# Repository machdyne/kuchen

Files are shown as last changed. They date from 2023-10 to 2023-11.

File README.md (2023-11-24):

# Kuchen Computer

Kuchen is an FPGA computer designed by Lone Dynamics Corporation.

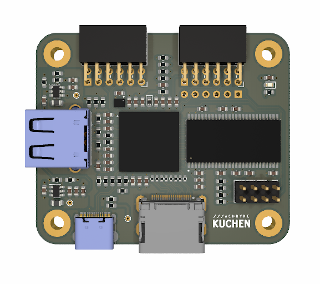
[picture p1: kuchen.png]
Kuchen FPGA Computer


This repo contains PCB layouts, schematics, pinouts, example gateware and documentation.

Find more information on the [Kuchen product page](https://machdyne.com/product/kuchen-computer/).

## Blinky 

Building the blinky example requires [Yosys](https://github.com/YosysHQ/yosys), [nextpnr-ice40](https://github.com/YosysHQ/nextpnr) and [IceStorm](https://github.com/YosysHQ/icestorm).

Assuming they are installed, you can simply type `make` to build the gateware, which will be written to output/blinky.bin. You can then use [ldprog](https://github.com/machdyne/ldprog) to write the gateware to the device over the ISP header, or use the USB DFU bootloader:

```
$ dfu-util -a 0 -D output/blinky.bin
```

Exit the bootloader and continue booting:

```
sudo dfu-util -e -a 0
```

## Zucker

[Zucker](https://github.com/machdyne/zucker) is a RISC-V SOC that supports Kuchen.

## USB Bootloader

Kuchen supports updating the flash MMOD over its USB-C port with the USB DFU (Device Firmware Upgrade) protocol. When Kuchen powers on (or restarts) the USB bootloader waits 5 seconds for a USB command and then continues the boot process, if it receives a command it will wait until the device is detached (with `dfu-util -e`) or rebooted (with `ldprog -r`).

Kuchen ships with the DFU bootloader on the MMOD. In order to re-install the USB bootloader you will need to use the ISP header and [ldprog](https://github.com/machdyne/ldprog). Make sure you have first installed the software required to build the Blinky example above.

```
git clone https://github.com/machdyne/tinydfu-bootloader
cd tinydfu-bootloader/boards/kuchen
make
make prog
```

Now you can program the flash MMOD over USB:

```
ldprog -r
sudo dfu-util -a 0 -D zucker/output/kuchen/soc.bin
sudo dfu-util -a 1 -D zucker/apps/lix/lix.bin
```

Exit the bootloader and continue booting:

```
sudo dfu-util -e -a 0
```

## ISP Header

The ISP header can be used to program the FPGA SRAM as well as the MMOD flash memory. 

```
7 5 3 1
8 6 4 2
```

| Pin | Signal |
| --- | --- |
| 1 | CSPI\_SS |
| 2 | CSPI\_SCK |
| 3 | CSPI\_SI |
| 4 | CSPI\_SO |
| 5 | CRESET |
| 6 | CDONE |
| 7 | GND |
| 8 | PWR5V0 |

## Board Revisions

| Revision | Notes |
| --- | ----- |
| V0 | Initial production boards |
| V1 | Move DQ7 from K14 to J14 |

## License

The contents of this repo are released under the [Lone Dynamics Open License](LICENSE.md).

Note: You can use these designs for commercial purposes but we ask that instead of producing exact clones, that you either replace our trademarks and logos with your own or add your own next to ours.

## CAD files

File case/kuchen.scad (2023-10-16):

/*
 * Kuchen Case
 * Copyright (c) 2023 Lone Dynamics Corporation. All rights reserved.
 *
 * required hardware:
 *  - 4 x M3 x 20mm countersunk bolts
 *  - 4 x M3 nuts
 *
 */

$fn = 100;

board_width = 50;
board_thickness = 1.5;
board_length = 60;
board_height = 1.6;
board_spacing = 2;

wall = 1.5;

top_height = 10;
bottom_height = 10;

//mdk_board();

//translate([0,0,15])
//	mdk_case_top();

translate([0,0,-15])
	mdk_case_bottom();

module mdk_board() {
	
	difference() {
		color([0,0.5,0])
			roundedcube(board_width,board_length,board_thickness,3);
		translate([5, 5, -1]) cylinder(d=3.2, h=10);
		translate([5, 55, -1]) cylinder(d=3.2, h=10);
		translate([45, 5, -1]) cylinder(d=3.2, h=10);
		translate([45, 55, -1]) cylinder(d=3.2, h=10);
	}	
	
}

module mdk_case_top() {
	
	difference() {
				
		color([0.5,0.5,0.5])
			roundedcube(board_width+(wall*2),board_length+(wall*2),top_height,2.5);

		// cutouts
			
		translate([2,9.5,-2])
			roundedcube(board_width-1.25,board_length-16,10.25,2.5);

		translate([9.5,3,-2])
			roundedcube(board_width-16,board_length-3,10.25,2.5);			
	
		translate([wall, wall, 0]) {

			// vents
			translate([50/2-(25/2),50,0]) cube([25,1,20]);
			translate([50/2-(25/2),45,0]) cube([25,1,20]);
			translate([50/2-(25/2),40,0]) cube([25,1,20]);			
	
			// USBC
			translate([30,14-(9.5/2),-1]) cube([30,9.5,3.5+1]);

			// HDMI
			translate([30,32-(15.5/2),-1]) cube([30,15.5,6.2+1]);
	
			// USBA
			translate([25-(15/2),-5,0]) cube([15,10,7.2+1]);
	

			// PMODA
			translate([-10,18.595-(16/2),0]) cube([25,16,5.1]);

			// PMODB
			translate([-10,41.455-(16/2),0]) cube([25,16,5.1]);
			
			// bolt holes
			translate([5, 5, -21]) cylinder(d=3.5, h=40);
			translate([5, 55, -21]) cylinder(d=3.5, h=40);
			translate([45, 5, -20]) cylinder(d=3.5, h=40);
			translate([45, 55, -21]) cylinder(d=3.5, h=40);

			// flush mount bolt holes
			translate([5, 5, top_height-1.5]) cylinder(d=5.25, h=4);
			translate([5, 55, top_height-1.5]) cylinder(d=5.25, h=4);
			translate([45, 5, top_height-1.5]) cylinder(d=5.25, h=4);
			translate([45, 55, top_height-1.5]) cylinder(d=5.25, h=4);

			// kuchen text
			rotate(270)
				translate([-18.5,25-3,top_height-0.5])
					linear_extrude(1)
						text("K U C H E N", size=4, halign="center",
							font="Ubuntu:style=Bold");

		}
		
	}	
}

module mdk_case_bottom() {
	
	difference() {
		color([0.5,0.5,0.5])
			roundedcube(board_width+(wall*2),board_length+(wall*2),bottom_height,2.5);
		
		// cutouts
		translate([3,10,1.5])
			roundedcube(board_width-3,board_length-17,10,2.5);
				
		translate([10.5,2.5,1.5])
			roundedcube(board_width-17.5,board_length-2,10,2.5);

		translate([wall, wall, 0]) {
			
		// board cutout
		translate([0,0,bottom_height-board_height])
			roundedcube(board_width+0.2,board_length+0.2,board_height+1,2.5);

		translate([wall, wall, 0]) {

			// USBC
			translate([38.5,14-(9.5/2),5]) cube([10.20,9.5,10.5+1]);

		}

		// bolt holes
		translate([5, 5, -11]) cylinder(d=3.2, h=25);
		translate([5, 55, -11]) cylinder(d=3.2, h=25);
		translate([45, 5, -11]) cylinder(d=3.2, h=25);
		translate([45, 55, -11]) cylinder(d=3.2, h=25);

		// nut holes
		translate([5, 5, -1]) cylinder(d=7, h=4, $fn=6);
		translate([5, 55, -1]) cylinder(d=7, h=4, $fn=6);
		translate([45, 5, -1]) cylinder(d=7, h=4, $fn=6);
		translate([45, 55, -1]) cylinder(d=7, h=4, $fn=6);

		}
		
	}	
}

// https://gist.github.com/tinkerology/ae257c5340a33ee2f149ff3ae97d9826
module roundedcube(xx, yy, height, radius)
{
    translate([0,0,height/2])
    hull()
    {
        translate([radius,radius,0])
        cylinder(height,radius,radius,true);

        translate([xx-radius,radius,0])
        cylinder(height,radius,radius,true);

        translate([xx-radius,yy-radius,0])
        cylinder(height,radius,radius,true);

        translate([radius,yy-radius,0])
        cylinder(height,radius,radius,true);
    }
}

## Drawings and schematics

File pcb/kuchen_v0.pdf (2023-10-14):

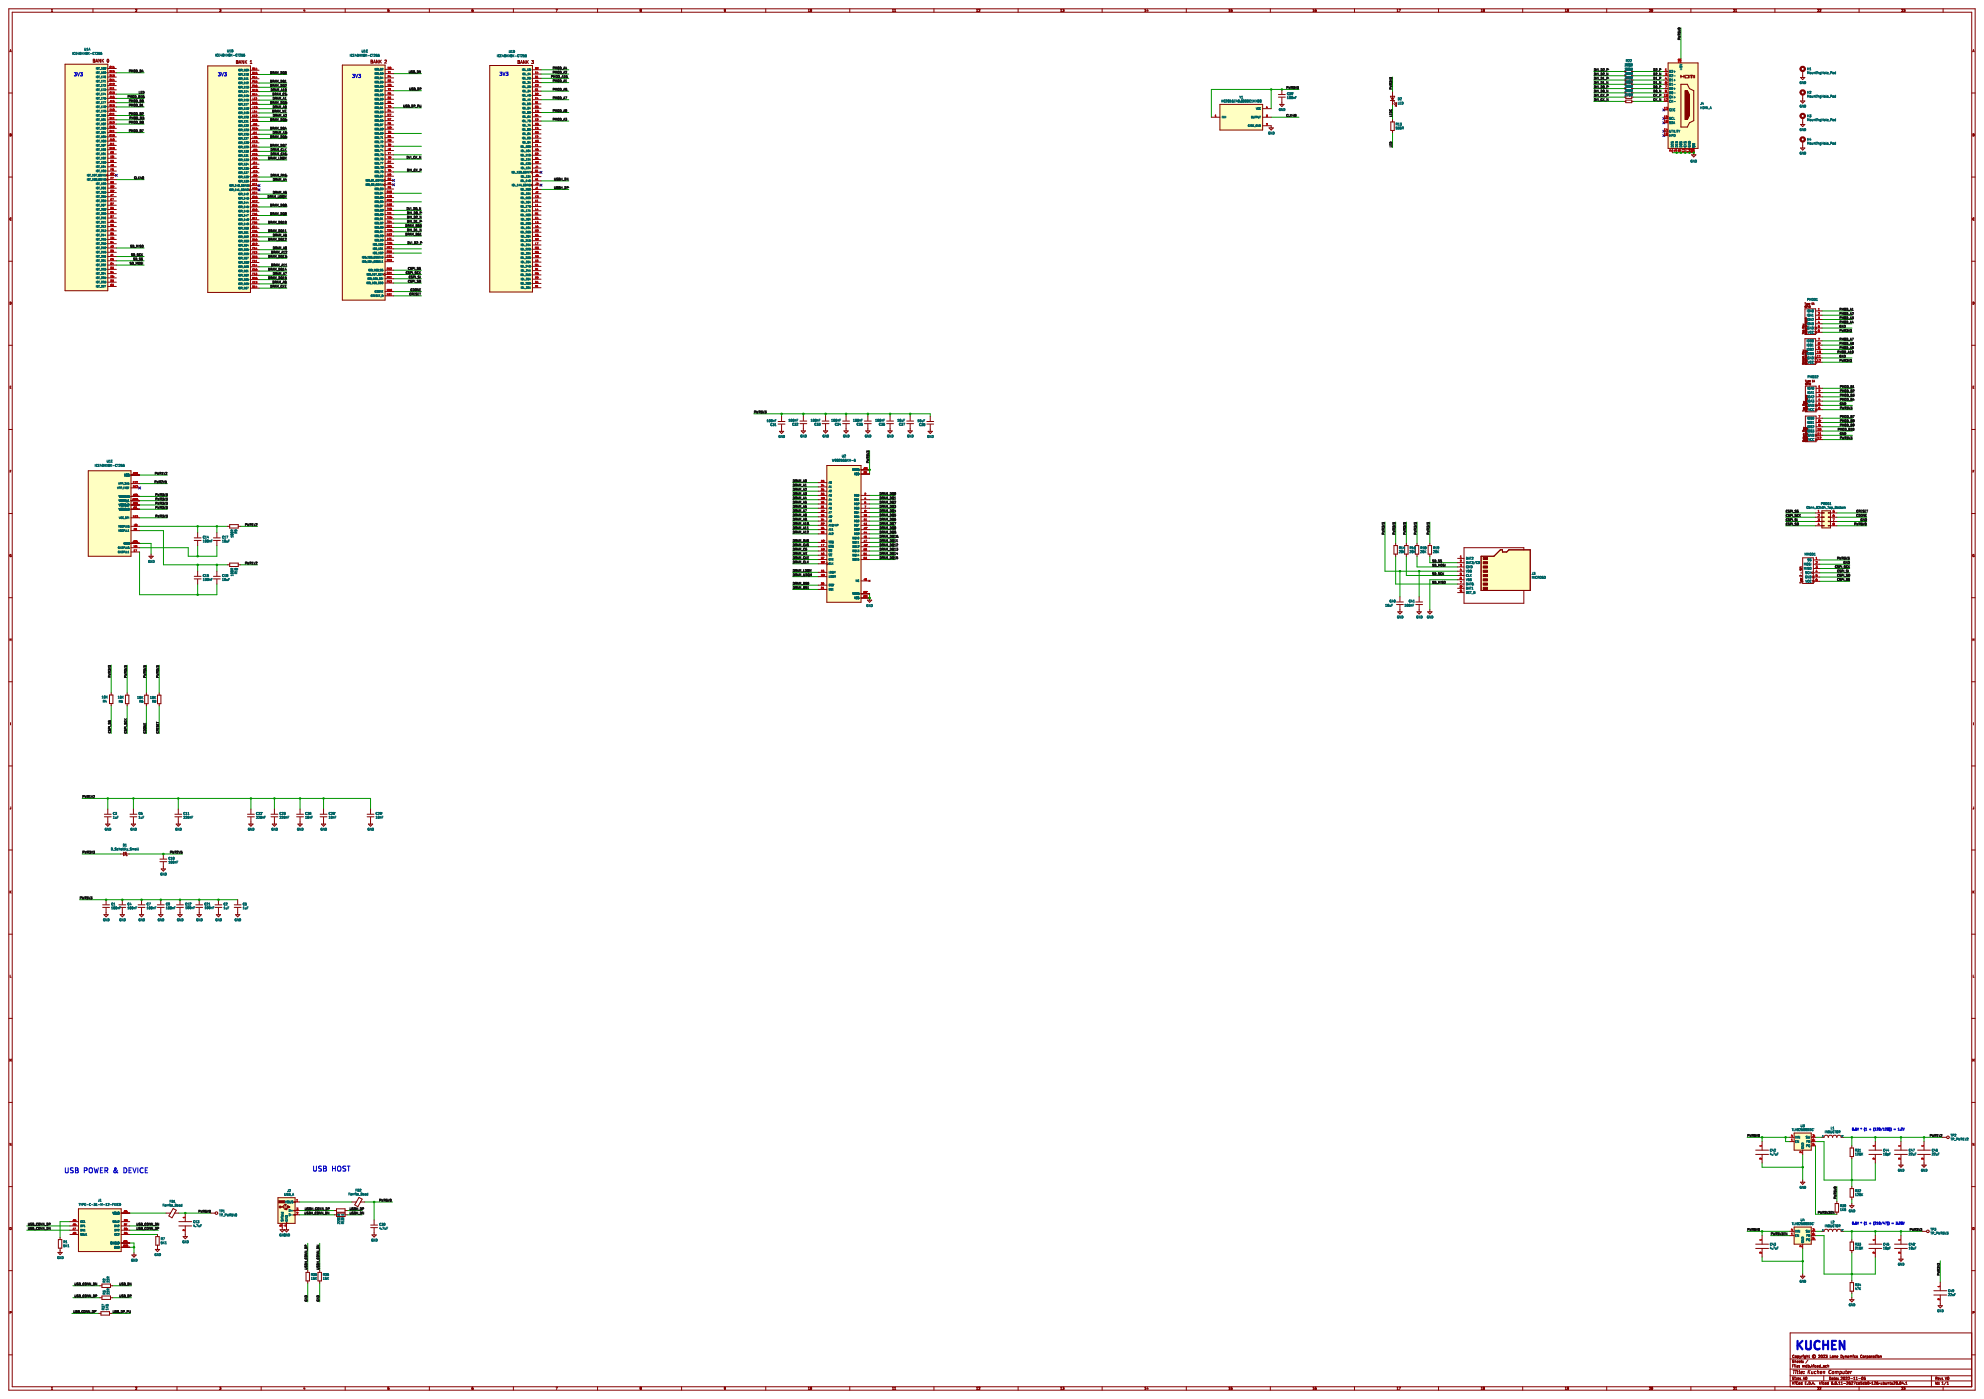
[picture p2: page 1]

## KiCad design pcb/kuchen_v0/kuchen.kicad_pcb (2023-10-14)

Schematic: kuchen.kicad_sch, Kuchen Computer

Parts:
C1, C4, C7, C9, C10, C12, C14, C15, C21, C31, C32, C33, C34, C35, C36, C39: 100nF; C_0603_1608Metric
C2, C3, C5, C6: 1uF; C_0603_1608Metric
C11, C22, C23: 220nF; C_0603_1608Metric
C13, C30: 4.7uF; R_0603_1608Metric
C17, C18, C37, C38, C48: 10uF; C_0603_1608Metric
C26, C28, C29: 10nF; C_0603_1608Metric
C40: 10uF; R_0603_1608Metric
C41: 100nF; R_0603_1608Metric
C42, C43: 4.7uF; C_0603_1608Metric
C44, C45: 10pF; C_0603_1608Metric
C46, C47, C49: 22uF; C_0603_1608Metric
D1: D_Schottky_Small; D_0603_1608Metric
D2: LED; LED_0603_1608Metric
FB1, FB2: Ferrite_Bead; R_0603_1608Metric
H1, H2, H3, H4: MountingHole_Pad; MountingHole_3.2mm_M3_Pad
J1: TYPE-C-31-M-12-FIXED; USB_C_Receptacle_HRO_TYPE-C-31-M-12-BIG-PADS; PARTREV A
J2: USB_A; USB_A_Stewart_SS-52100-001_Horizontal
J3: MICROSD; TF-018B-H15
J4: HDMI_A; HDMI_TE_1827059-3-FIXED
L1, L2: INDUCTOR; L_0805_2012Metric
MMOD1: PMOD-Device-x1-Type-2-SPI; PinSocket_1x06_P2.54mm_Horizontal
PMOD1, PMOD2: PMOD-Device-x2-Type-1A-GPIO; PMOD_2x06_HOST
PROG1: Conn_02x04_Top_Bottom; PinHeader_2x04_P2.54mm_Vertical
R1, R7: 5K1; R_0603_1608Metric
R2, R3, R11, R12: 22R; R_0603_1608Metric
R4, R5, R6, R8: 10K; R_0603_1608Metric
R9, R10: 100R; R_0603_1608Metric
R13: 536R; R_0603_1608Metric
R14, R16, R18, R19: 20K; R_0603_1608Metric
R22, R23, R24, R25, R26, R27, R28, R29: 270R; R_0402_1005Metric
R30, R37: 1K5; R_0603_1608Metric
R31, R32: 120K; R_0603_1608Metric
R33: 210K; R_0603_1608Metric
R34: 47K; R_0603_1608Metric
R35, R36: 15K; R_0603_1608Metric
TP1: TP_PWR5V0; TestPoint_THTPad_D1.0mm_Drill0.5mm
TP2: TP_PWR1V2; TestPoint_THTPad_D1.0mm_Drill0.5mm
TP3: TP_PWR3V3; TestPoint_THTPad_D1.0mm_Drill0.5mm
U1: ICE40HX8K-CT256; BGA256C80P16X16_1400X1400X170; PART_REV 3.4
U2: W9825G6KH-6; SOP80P1176X120-54N; PARTREV A05
U3, U4: TLV62568DDC; SOT-23-6
Y1: KC2016Z48.0000C1KX00; OSC_KC2016Z13.5600C1KX00; PARTREV November 2020

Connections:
/CDONE: PROG1.6, R6.1, U1.M10 (CDONE)
/CK_N: J4.12 (CK-), R29.2
/CK_P: J4.10 (CK+), R28.2
/CLK48: U1.F7 (IOT_198_GBIN0), Y1.3 (OUTPUT)
/CRESET: PROG1.5, R8.1, U1.N11 (CRESET_B)
/CSPI_SCK: MMOD1.3 (MISO), PROG1.2, R5.1, U1.R11 (IOB_107_SCK)
/CSPI_SI: MMOD1.4 (SCK), PROG1.3, U1.P11 (IOB_106_SDI)
/CSPI_SO: MMOD1.5 (GND), PROG1.4, U1.P12 (IOB_105_SDO)
/CSPI_SS: MMOD1.6 (VCC), PROG1.1, R4.1, U1.R12 (IOB_108_SS)
/D0_N: J4.9 (D0-), R27.2
/D0_P: J4.7 (D0+), R26.2
/D1_N: J4.6 (D1-), R25.2
/D1_P: J4.4 (D1+), R24.2
/D2_N: J4.3 (D2-), R23.2
/D2_P: J4.1 (D2+), R22.2
/DRAM_A0: U1.L13 (IOR_118), U2.23 (A0)
/DRAM_A1: U1.L12 (IOR_116), U2.24 (A1)
/DRAM_A2: U1.K12 (IOR_120), U2.25 (A2)
/DRAM_A3: U1.J11 (IOR_126), U2.26 (A3)
/DRAM_A4: U1.H13 (IOR_139), U2.29 (A4)
/DRAM_A5: U1.H14 (IOR_142), U2.30 (A5)
/DRAM_A6: U1.G13 (IOR_152), U2.31 (A6)
/DRAM_A7: U1.F13 (IOR_162), U2.32 (A7)
/DRAM_A8: U1.F14 (IOR_155), U2.33 (A8)
/DRAM_A9: U1.E13 (IOR_166), U2.34 (A9)
/DRAM_A10: U1.M13 (IOR_114), U2.22 (A10/AP)
/DRAM_A11: U1.E14 (IOR_160), U2.35 (A11)
/DRAM_A12: U1.F12 (IOR_156), U2.36 (A12)
/DRAM_BS0: U1.M11 (IOB_93), U2.20 (BS0)
/DRAM_BS1: U1.N12 (IOB_98), U2.21 (BS1)
/DRAM_CAS: U1.K15 (IOR_131), U2.17 (~CAS)
/DRAM_CKE: U1.D14 (IOR_167), U2.37 (CKE)
/DRAM_CLK: U1.J15 (IOR_130), U2.38 (CLK)
/DRAM_CS: U1.M14 (IOR_115), U2.19 (~CS)
/DRAM_DQ0: U1.R15 (IOR_110), U2.2 (DQ0)
/DRAM_DQ1: U1.P15 (IOR_112), U2.4 (DQ1)
/DRAM_DQ2: U1.P16 (IOR_113), U2.5 (DQ2)
/DRAM_DQ3: U1.N16 (IOR_117), U2.7 (DQ3)
/DRAM_DQ4: U1.M15 (IOR_123), U2.8 (DQ4)
/DRAM_DQ5: U1.M16 (IOR_121), U2.10 (DQ5)
/DRAM_DQ6: U1.L16 (IOR_127), U2.11 (DQ6)
/DRAM_DQ7: U1.K14 (IOR_129), U2.13 (DQ7)
/DRAM_DQ8: U1.G15 (IOR_145), U2.42 (DQ8)
/DRAM_DQ9: U1.F16 (IOR_147), U2.44 (DQ9)
/DRAM_DQ10: U1.F15 (IOR_149), U2.45 (DQ10)
/DRAM_DQ11: U1.E16 (IOR_151), U2.47 (DQ11)
/DRAM_DQ12: U1.D16 (IOR_153), U2.48 (DQ12)
/DRAM_DQ13: U1.D15 (IOR_157), U2.50 (DQ13)
/DRAM_DQ14: U1.C16 (IOR_161), U2.51 (DQ14)
/DRAM_DQ15: U1.B16 (IOR_165), U2.53 (DQ15)
/DRAM_LDQM: U1.K16 (IOR_133), U2.15 (LDQM)
/DRAM_RAS: U1.J16 (IOR_138), U2.18 (~RAS)
/DRAM_UDQM: U1.G16 (IOR_143), U2.39 (UDQM)
/DRAM_WE: U1.L14 (IOR_119), U2.16 (~WE)
/DVI_CK_N: R29.1, U1.T8 (IOB_76)
/DVI_CK_P: R28.1, U1.T9 (IOB_79)
/DVI_D0_N: R27.1, U1.T10 (IOB_88)
/DVI_D0_P: R26.1, U1.T11 (IOB_89)
/DVI_D1_N: R25.1, U1.T13 (IOB_94)
/DVI_D1_P: R24.1, U1.T14 (IOB_92)
/DVI_D2_N: R23.1, U1.T15 (IOB_91)
/DVI_D2_P: R22.1, U1.T16 (IOB_100)
/LED: R13.2, U1.C13 (IOT_174)
/LEDC: D2.1 (K), R13.1
/PMOD_A1: PMOD1.1 (IOA0), U1.F5 (IOL_2A)
/PMOD_A2: PMOD1.2 (IOA1), U1.E4 (IOL_1A)
/PMOD_A3: PMOD1.3 (IOA2), U1.E2 (IOL_7B)
/PMOD_A4: PMOD1.4 (IOA3), U1.B2 (IOL_1B)
/PMOD_A7: PMOD1.7 (IOB0), U1.F4 (IOL_4A)
/PMOD_A8: PMOD1.8 (IOB1), U1.E3 (IOL_6B)
/PMOD_A9: PMOD1.9 (IOB2), U1.C1 (IOL_3A)
/PMOD_A10: PMOD1.10 (IOB3), U1.B1 (IOL_2B)
/PMOD_B1: PMOD2.1 (IOA0), U1.B13 (IOT_178)
/PMOD_B2: PMOD2.2 (IOA1), U1.C11 (IOT_180)
/PMOD_B3: PMOD2.3 (IOA2), U1.D11 (IOT_181)
/PMOD_B4: PMOD2.4 (IOA3), U1.B15 (IOT_169)
/PMOD_B7: PMOD2.7 (IOB0), U1.B11 (IOT_184)
/PMOD_B8: PMOD2.8 (IOB1), U1.B12 (IOT_182)
/PMOD_B9: PMOD2.9 (IOB2), U1.A15 (IOT_177)
/PMOD_B10: PMOD2.10 (IOB3), U1.A16 (IOT_176)
/PWR1V2: C3.1, C6.1, C11.1, C22.1, C23.1, C26.1, C28.1, C29.1, C44.1, C46.1, C47.1, L1.2, R9.1, R10.1, R31.1, TP2.1, U1.A14 (VCC), U1.F6 (VCC), U1.F10 (VCC), U1.K6 (VCC), U1.K10 (VCC), U1.L2 (VCC)
/PWR2V5: C10.1, D1.1 (K), U1.E12 (VPP_2V5)
/PWR3V3: C1.1, C2.1, C4.1, C5.1, C7.1, C9.1, C12.1, C21.1, C31.2, C32.2, C33.2, C34.2, C35.2, C36.2, C37.2, C38.2, C39.1, C40.1, C41.1, C45.1, C48.1, C49.1, D1.2 (A), D2.2 (A), J3.4 (VDD), L2.2, MMOD1.1 (SS), PMOD1.6 (VCC), PMOD1.12 (VCC), PMOD2.6 (VCC), PMOD2.12 (VCC), R4.2, R5.2, R6.2, R8.2, R14.1, R16.1, R18.1, R19.1, R33.1, TP3.1, U1.A3 (VCCIO_0), U1.A8 (VCCIO_0), U1.A13 (VCCIO_0), U1.C15 (VCCIO_1), U1.E1 (VCCIO_3), U1.F8 (VCCIO_0), U1.G6 (VCCIO_3), U1.H10 (VCCIO_1), U1.H15 (VCCIO_1), U1.J6 (VCCIO_3), U1.K8 (VCCIO_2), U1.N1 (VCCIO_3), U1.N13 (VCC_SPI), U1.N15 (VCCIO_1), U1.P3 (VCCIO_2), U1.R8 (VCCIO_2), U1.R13 (VCCIO_2), U2.1 (VDD), U2.3 (VDDQ), U2.9 (VDDQ), U2.14 (VDD), U2.27 (VDD), U2.43 (VDDQ), U2.49 (VDDQ), Y1.1 (INH), Y1.4 (VCC)
/PWR3V3EN: R30.2, U3.5 (PG), U4.1 (EN)
/PWR5V0: C13.1, C30.1, C42.1, C43.1, FB1.1, FB2.1, J4.18 (+5V), PROG1.8, R30.1, TP1.1, U3.1 (EN), U3.4 (VIN), U4.4 (VIN)
/SD_MISO: J3.7 (DAT0), R14.2, U1.A2 (IOT_218)
/SD_MOSI: J3.3 (CMD), R18.2, U1.C4 (IOT_222)
/SD_SCK: J3.5 (CLK), R16.2, U1.A1 (IOT_220)
/SD_SS: J3.2 (DAT3/CD), R19.2, U1.C5 (IOT_221)
/USBH_CONN_DN: J2.2 (D-), R12.2, R36.1
/USBH_CONN_DP: J2.3 (D+), R11.2, R35.1
/USBH_DN: R12.1, U1.H1 (IOL_14B)
/USBH_DP: R11.1, U1.J1 (IOL_15B)
/USB_CONN_DN: J1.A7 (DN1), J1.B7 (DN2), R2.1
/USB_CONN_DP: J1.A6 (DP1), J1.B6 (DP2), R3.1, R37.1
/USB_DN: R2.2, U1.T1 (IOB_53)
/USB_DP: R3.2, U1.T2 (IOB_57)
/USB_DP_PU: R37.2, U1.T3 (IOB_61)
GND: C1.2, C2.2, C3.2, C4.2, C5.2, C6.2, C7.2, C9.2, C10.2, C11.2, C12.2, C13.2, C21.2, C22.2, C23.2, C26.2, C28.2, C29.2, C30.2, C31.1, C32.1, C33.1, C34.1, C35.1, C36.1, C37.1, C38.1, C39.2, C40.2, C41.2, C42.2, C43.2, C46.2, C47.2, C48.2, C49.2, H1.1, H2.1, H3.1, H4.1, J1.A1 (GND), J1.A12 (GND), J1.B1 (GND), J1.B12 (GND), J1.S1 (SHIELD), J1.S2 (SHIELD), J1.S3 (SHIELD), J1.S4 (SHIELD), J2.4 (GND), J2.5 (Shield), J3.6 (VSS), J4.2 (D2S), J4.5 (D1S), J4.8 (D0S), J4.11 (CKS), J4.17 (GND), J4.S1 (SH), J4.S2 (SH), J4.S3 (SH), J4.S4 (SH), MMOD1.2 (MOSI), PMOD1.5 (GND), PMOD1.11 (GND), PMOD2.5 (GND), PMOD2.11 (GND), PROG1.7, R1.2, R7.2, R32.2, R34.2, R35.2, R36.2, U1.A4 (GND), U1.A12 (GND), U1.E15 (GND), U1.G7 (GND), U1.G8 (GND), U1.G9 (GND), U1.H7 (GND), U1.H8 (GND), U1.H9 (GND), U1.J7 (GND), U1.J8 (GND), U1.J9 (GND), U1.K2 (GND), U1.K7 (GND), U1.L15 (GND), U1.R7 (GND), U1.T4 (GND), U1.T12 (GND), U2.6 (VSSQ), U2.12 (VSSQ), U2.28 (VSS), U2.41 (VSS), U2.46 (VSSQ), U2.52 (VSSQ), U2.54 (VSS), U3.2 (GND), U4.2 (GND), Y1.2 (CASE_GND)
unnamed: C14.1, C17.1, R9.2, U1.L8 (VCCPLL0)
unnamed: C14.2, C17.2, U1.N8 (GNDPLL0)
unnamed: C15.1, C18.1, R10.2, U1.E8 (VCCPLL1)
unnamed: C15.2, C18.2, U1.E7 (GNDPLL1)
unnamed: C44.2, R31.2, R32.1, U3.6 (FB)
unnamed: C45.2, R33.2, R34.1, U4.6 (FB)
unnamed: FB1.2, J1.A4 (VBUS), J1.A9 (VBUS), J1.B4 (VBUS), J1.B9 (VBUS)
unnamed: FB2.2, J2.1 (VBUS)
unnamed: J1.A5 (CC1), R1.1
unnamed: J1.B5 (CC2), R7.1
unnamed: L1.1, U3.3 (SW)
unnamed: L2.1, U4.3 (SW)

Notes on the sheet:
0.6V * (1 + (120/120)) = 1.2V
3V3
KUCHEN
0.6V * (1 + (210/47)) = 3.28V
USB HOST
USB POWER & DEVICE

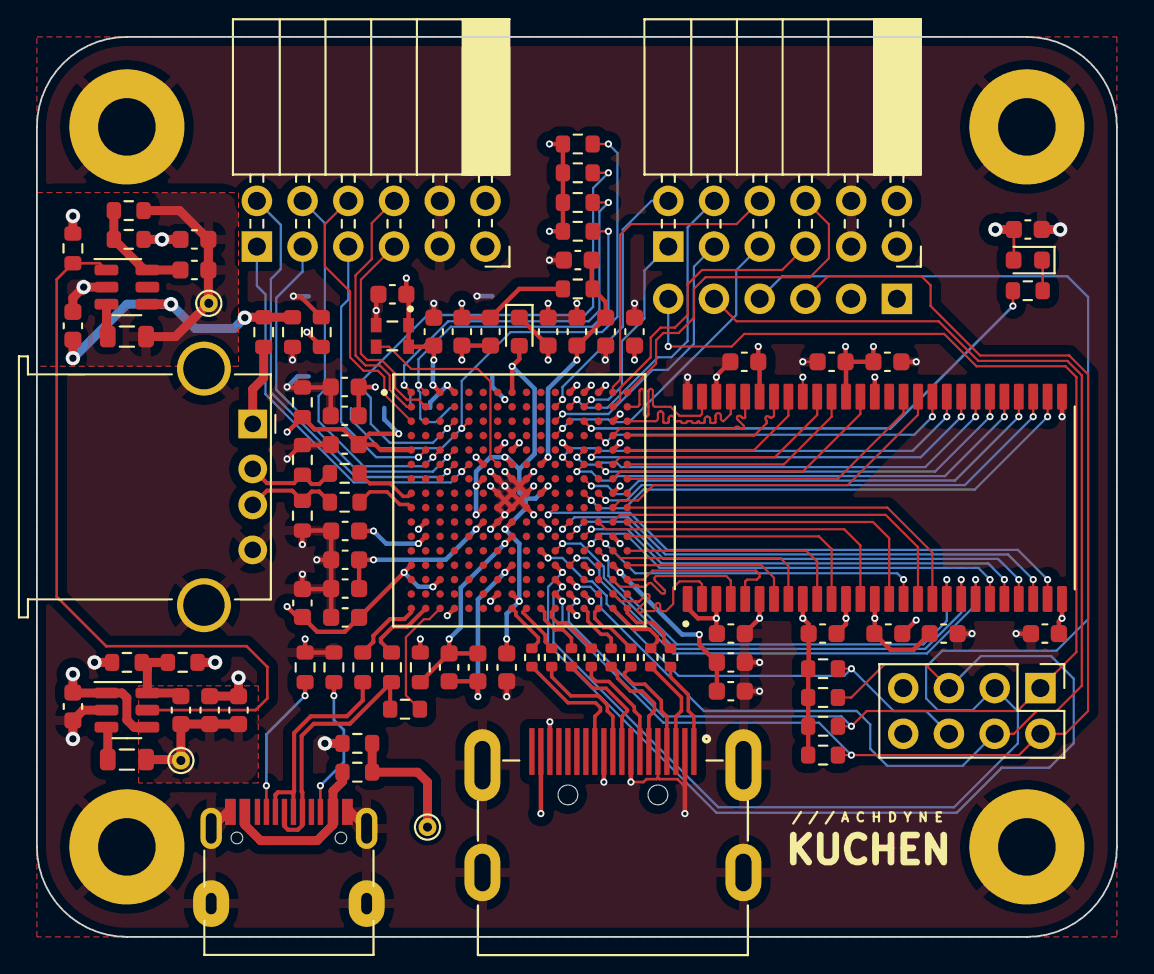
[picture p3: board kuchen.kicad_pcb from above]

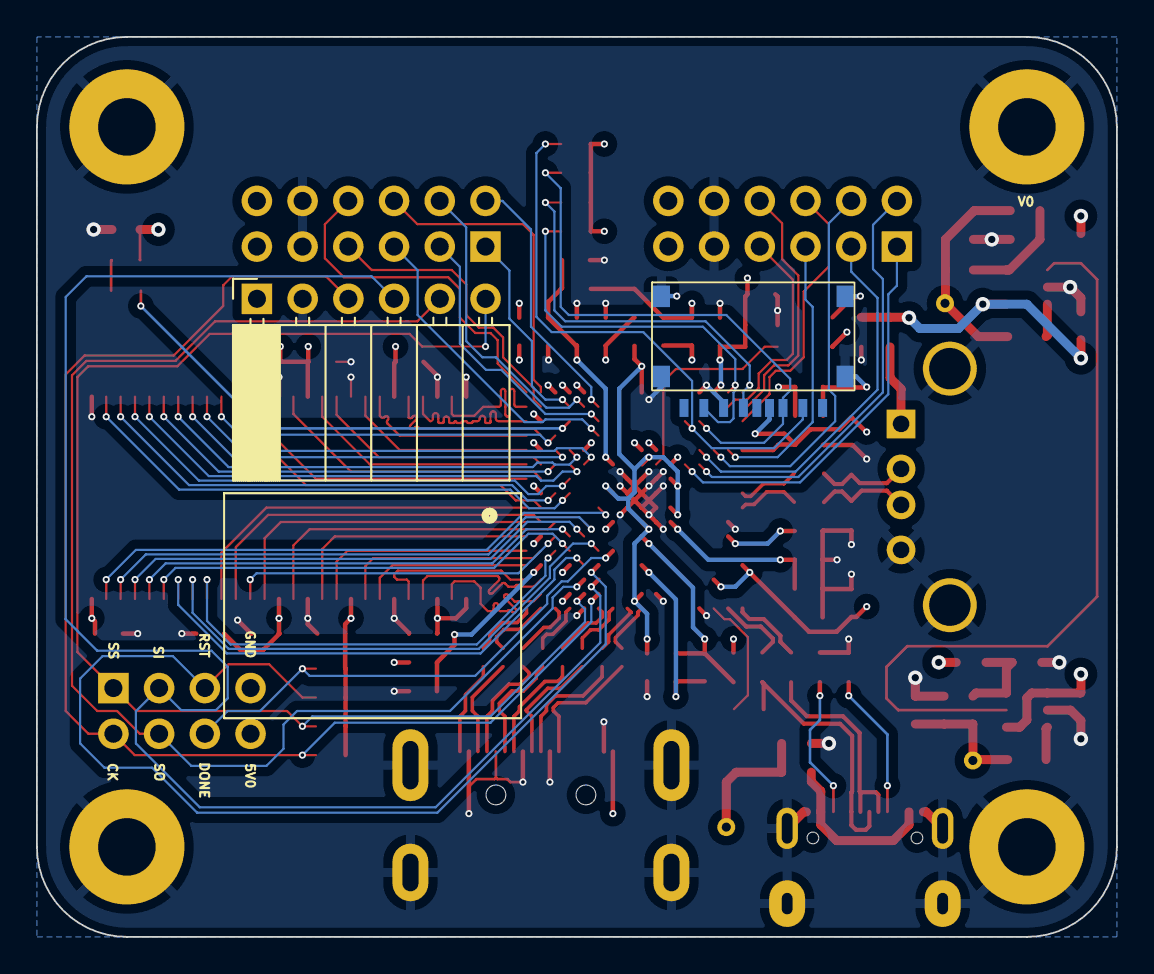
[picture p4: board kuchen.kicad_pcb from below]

Board: 4 copper layers, 60.0 x 50.0 mm, 101 parts (2 on the bottom side), 111 nets.

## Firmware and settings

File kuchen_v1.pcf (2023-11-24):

# Kuchen V0
# ---------

set_io CLK_48		F7

set_io LED			C13

# PMOD A
set_io PMOD_A1		F5
set_io PMOD_A2		E4
set_io PMOD_A3		E2
set_io PMOD_A4		B2
set_io PMOD_A7		F4
set_io PMOD_A8		E3
set_io PMOD_A9		C1
set_io PMOD_A10	B1

# PMODB
set_io PMOD_B1		B13
set_io PMOD_B2		C11
set_io PMOD_B3		D11
set_io PMOD_B4		B15
set_io PMOD_B7		B11
set_io PMOD_B8		B12
set_io PMOD_B9		A15
set_io PMOD_B10	A16

# USB-UART on PMODB
set_io UART0_RTS  B13
set_io UART0_RX   C11
set_io UART0_TX   D11
set_io UART0_CTS  B15

# SDRAM
set_io sdram_dq[0]	R15
set_io sdram_dq[1]	P15
set_io sdram_dq[2]	P16
set_io sdram_dq[3]	N16
set_io sdram_dq[4]	M15
set_io sdram_dq[5]	M16
set_io sdram_dq[6]	L16
set_io sdram_dq[7]	J14
set_io sdram_dq[8]	G15
set_io sdram_dq[9]	F16
set_io sdram_dq[10]	F15
set_io sdram_dq[11]	E16
set_io sdram_dq[12]	D16
set_io sdram_dq[13]	D15
set_io sdram_dq[14]	C16
set_io sdram_dq[15]	B16
set_io sdram_dm[0]	K16
set_io sdram_dm[1]	G16
set_io sdram_cke	D14
set_io sdram_clock	J15
set_io sdram_cas_n	K15
set_io sdram_ras_n	J16
set_io sdram_cs_n		M14
set_io sdram_we_n		L14
set_io sdram_ba[0]	M11
set_io sdram_ba[1]	N12
set_io sdram_a[0]		L13
set_io sdram_a[1]		L12
set_io sdram_a[2]		K12
set_io sdram_a[3]		J11
set_io sdram_a[4]		H13
set_io sdram_a[5]		H14
set_io sdram_a[6]		G13
set_io sdram_a[7]		F13
set_io sdram_a[8]		F14
set_io sdram_a[9]		E13
set_io sdram_a[10]	M13
set_io sdram_a[11]	E14
set_io sdram_a[12]	F12

# DDMI
set_io DDMI_D0_N	T10
set_io DDMI_D1_N	T13
set_io DDMI_D2_N	T15
set_io DDMI_CK_N	T8
set_io DDMI_D0_P	T11
set_io DDMI_D1_P	T14
set_io DDMI_D2_P	T16
set_io DDMI_CK_P	T9

# MicroSD
set_io SD_SS	C5
set_io SD_MISO	A2
set_io SD_MOSI	C4
set_io SD_SCK	A1

# USB-C DEVICE
set_io USB_DN		T1
set_io USB_DP		T2
set_io USB_DP_PU	T3

# USB-A HOST
set_io USBH_DN		H1
set_io USBH_DP		J1

# CONFIG SPI
set_io SPI_SS		R12
set_io SPI_SCK		R11
set_io SPI_MISO	P11	# CSPI_SI
set_io SPI_MOSI	P12	# CSPI_SO

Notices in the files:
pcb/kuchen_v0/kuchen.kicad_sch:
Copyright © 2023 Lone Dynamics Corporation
